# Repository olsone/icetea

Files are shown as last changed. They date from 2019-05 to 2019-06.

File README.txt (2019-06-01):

===== Compiling =======

To compile chip.bin:

make

To send it to BlackIce-II (standard firmware)

Terminal 1:
cat < /dev/cu.usbmodem1421
or:
make tty

Terminal 2:
stty -f /dev/cu.usbmodem1421 raw
cat chip.bin > /dev/cu.usbmodem1421
or:
make upload

stored in blackice.mk

======= PLL =========

Colorburst frequency of 315/88 MHz is made (x8 factor) by:

icepll -o 28.636363 -i 100 -m -f pll_ntsc.v

F_PLLIN:   100.000 MHz (given)
F_PLLOUT:   28.636 MHz (requested)
F_PLLOUT:   28.646 MHz (achieved)

FEEDBACK: SIMPLE
F_PFD:   16.667 MHz
F_VCO:  916.667 MHz

DIVR:  5 (4'b0101)
DIVF: 54 (7'b0110110)
DIVQ:  5 (3'b101)

FILTER_RANGE: 1 (3'b001)

	reg [5:0] count;

//	assign gplclock_out = count[2]; // 3.579545 MHz,  actual 3.580750
	assign sndclock_out = count[5]; // 447.443 KHz, actual 447.593 KHz

	always @(posedge clock8x)
	    if (!locked)
	        count = 0;
	    else
		    count <= count + 1;

========================

Pin assignments in icetea.pcf are customized from blaceice-ii.pcf

Using PMOD7-12 to connect to the IceTea board
Using PMOD6 to connect to PMOD I2S

========================

Structure

chip.v 
\____pll_ntsc.v
\____memory_interface.v ==/== SRAM
\____sn76489 
     \____i2s

===================

Weird errors

ERROR: Mismatch in directionality for cell port chip.dig_snd_out.mclk: \PMOD [20] <= \dig_snd_out.mclk
caused by assigning Z to it somewhere:
  assign PMOD[20:0] = {20{1'bz}};

Warning: Driver-driver conflict for \dig_snd_out.value [7] between cell $techmap\dig_snd_out.$procdff$1731.Q and constant 1'0 in chip: Resolved using constant.
caused by assigning value=0 in akways(reset) and in always(negedge clk)

shift_ctrl.v:17: Warning: Identifier `\count_n' is implicitly declared.

this might be why shift_reset toggles.
 assign count_n = count + 1; always made shift_reset oscillate.

Shift Registers. Did'nt work consistently until I halved the clock rate to 25 MHz.
It now takes 300 ns to decode the address.
===================

Helpful tools

play many loops of a 1-cycle sample:

sox AKWF_symetric/AKWF_symetric_0001.wav -d repeat 180

Like
AKWF_piano/AKWF_piano_0001.wav
AKWF_bw_saw/AKWF_saw_0002.wav

sox AKWF_cello/AKWF_cello_0003.wav -d repeat 100 tremolo 6

sox AKWF_violin/AKWF_violin_0005.wav -d repeat 100 

dumpwav ~/Downloads/AKWF_violin/AKWF_violin_0005.wav > waves/wave_violin.mem

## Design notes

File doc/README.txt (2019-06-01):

===== Compiling =======

To compile chip.bin:

make

To send it to BlackIce-II (standard firmware)

Terminal 1:
cat < /dev/cu.usbmodem1421
or:
make tty

Terminal 2:
stty -f /dev/cu.usbmodem1421 raw
cat chip.bin > /dev/cu.usbmodem1421
or:
make upload

stored in blackice.mk

======= PLL =========

Colorburst frequency of 315/88 MHz is made (x8 factor) by:

icepll -o 28.636363 -i 100 -m -f pll_ntsc.v

F_PLLIN:   100.000 MHz (given)
F_PLLOUT:   28.636 MHz (requested)
F_PLLOUT:   28.646 MHz (achieved)

FEEDBACK: SIMPLE
F_PFD:   16.667 MHz
F_VCO:  916.667 MHz

DIVR:  5 (4'b0101)
DIVF: 54 (7'b0110110)
DIVQ:  5 (3'b101)

FILTER_RANGE: 1 (3'b001)

	reg [5:0] count;

//	assign gplclock_out = count[2]; // 3.579545 MHz,  actual 3.580750
	assign sndclock_out = count[5]; // 447.443 KHz, actual 447.593 KHz

	always @(posedge clock8x)
	    if (!locked)
	        count = 0;
	    else
		    count <= count + 1;

========================

Pin assignments in icetea.pcf are customized from blaceice-ii.pcf

Using PMOD7-12 to connect to the IceTea board
Using PMOD6 to connect to PMOD I2S

========================

Structure

chip.v 
\____pll_ntsc.v
\____memory_interface.v ==/== SRAM
\____sn76489 
     \____i2s

===================

Testbench

brew install icarus-verilog

cat > testbench.mk

shift_tb: shift_ser_in.v shift_tb.v shift74ls165.v
				iverilog -o $@ shift_ser_in.v shift_tb.v shift74ls165.v

make shift_tb

vvp shift_tb

===================

Weird errors

ERROR: Mismatch in directionality for cell port chip.dig_snd_out.mclk: \PMOD [20] <= \dig_snd_out.mclk
caused by assigning Z to it somewhere:
  assign PMOD[20:0] = {20{1'bz}};

Warning: Driver-driver conflict for \dig_snd_out.value [7] between cell $techmap\dig_snd_out.$procdff$1731.Q and constant 1'0 in chip: Resolved using constant.
caused by assigning value=0 in akways(reset) and in always(negedge clk)

shift_ctrl.v:17: Warning: Identifier `\count_n' is implicitly declared.

this might be why shift_reset toggles.
 assign count_n = count + 1; always made shift_reset oscillate.

Shift Registers. Did'nt work consistently until I halved the clock rate to 25 MHz.
It now takes 300 ns to decode the address.

BUG Icarus says
  shift_ser_in ser1 (.i_q(adrin1), .i_reset(o_shld), .i_serclk(o_serclk), .o_data(addr_reg[15:8]))
memory_interface.v:297: error: Output port expression must support continuous assignment.
memory_interface.v:297:      : Port 4 (o_data) of shift_ser_in is connected to addr_reg['sd15:'sd8]

addr_reg cannot be a reg. Change to wire. ADDRESS_DECODE can unscramble it into a reg.

BUG
Warning: multiple conflicting drivers for chip.\mem.chip_select:
did you write 'else' not 'else begin/end':
if (reset) begin
  a = 0;
  b = 0;
  end else
  a = 0
b = 0
   
===================

Helpful tools

play many loops of a 1-cycle sample:

sox AKWF_symetric/AKWF_symetric_0001.wav -d repeat 180

Like
AKWF_piano/AKWF_piano_0001.wav
AKWF_bw_saw/AKWF_saw_0002.wav

sox AKWF_cello/AKWF_cello_0003.wav -d repeat 100 tremolo 6

sox AKWF_violin/AKWF_violin_0005.wav -d repeat 100 

dumpwav ~/Downloads/AKWF_violin/AKWF_violin_0005.wav > waves/wave_violin.mem

================
Signal integrity
================
Confirmed that IAQ is good, and there is a crosstalk glitch in the VB cable.

snapshots 12/4/18 9:24 pm
1) iaq (mistakenly connected on d30 bmemen)

===
decode
56c4 = 7d01 read iaq
56d4 = 7d03 read 
56cc = 7d05 read iaq
56dc = 7d07 read
56e4 = 7d09 read iaq
56f4 = 7d0b read 
4c00 = a001 read
4c00 = a001 write
56ec = 7d0d read

perfect!

0400 = 0001 read
04d0 = 0c03 read iaq
04f0 = 0c0b read iaq

BLWP @>0000

0400 = 0001 read
af3b = 83ff write, so WP = 83E0 
af2b = 83fd write
af33 = 83fb write
0410 = 0003 read 
0409 = 0025 read iaq

0400 = 0001 read
0400 = 0001 read iaq
0410 = 0003 read
0409 = 0025 read
bc18 = c247 read

...

af01 = 83e1 read IAQ
051b = 00b7 read
bc18 = c247 write

0523 = 00b9 read
a77b = 0bff read IAQ
3c29 = c22d write

... last instruction

0c44 = 9801 read 

FREEZING - f18a title displays - the last thing executed was read from GRMRD
icetea is trying to respond at every address.

in VB, srclk glitches, shifting addr right one bit

8641 = 0961 read iaq
af31 = 83eb
a473 = 0a7b

  LIMI 0
  SETO @>A000
  JMP $-4
  
encoded / decoded / memory content  
 7D00  0300
 7D02  0000
56cc 7D04  0720 read iaq
56DC 7D06  A000 read
56E4 7D08  10FD read iaq

4c00 a001
4800 a000

spis addr page
4800 a000 8 wrong
56cc 7d05 c wrong
56cc 7d05 4 wrong
56dc 7d07 7 wrong
56dc 7d07 6 wrong
4800 a000  
56cc 7d05 4 wrong
4c00 a001 0 wrong
56e4 7d09 8 wrong
56cc 7d05 4 wrong

af11 83e3 2 wrong
a62b 037d 2 wrong
261b 0337 2 wrong
2623 0339 2 wrong
af30 83cb a wrong
2721 03a9 2 wrong

Next iteration. use wire addr_in, not reg addr_reg

spis addr page
af11 83e3 a wrong
af21 83e9 a wrong

a62b 037d 2 wrong
4c00 a001 a right
56cc 7d05 7 right
8642 0951 2 wrong
261b 0337 2 wrong

maybe internal cycle is too fast?
8409 0064 xx6x
8421 0068 xx6x 
8403 0070 xx7x
842b 007c xxxC
843a 005e xxxE
2528 028c xxxC
2530 028a xExx
251a 0296 xExx
2522 0298 xExx
2623 0339 2xxx
2633 033a 2x1A
263b 033e xxxE
a618 0347 2xxx

ae2b 837c xx7x
af32 83da xFxx
af11 83e2 Axxx
af21 83e9 AFxx wrong
af31 83ea xFxx
af29 83ec xFEC
af13 83f3 xFxA
af23 83f8 Axxx
af33 83fb xFFx

0cd4 9c02 xx4x  GRMWA
0c44 9800 xExx  GRMRD
read from 9c02: 2 us
write to 9c02: 10 us
read from 9800: 10 us

almost like its not unscrambling the top byte

i moved leds to the bottom of chip.v and in page 0 addresses
8409 0064 x0xx
8419 x0xx
af29 83ec x0xx
af33 83fb x0xx
0cd4 xCxx

test writes to all pages
7D00 LIMI 0
7D02 
7D04 CLR R0

Spi  Addr

56dc 7D06 SETO *R0
56E4 7D08 AI R0,>2000
56f4 7D0A
56ec 7D0C JMP $-8

0400 0 2
0404 1 3
4400 2 2
4404 3 3
1400 4 6
1404 5 7
5400 6 6
5404 7 7
0c00 8 a
0c04 9 b
4c00 a a
4c04 b b
1c00 c e
1c04 d f
5c00 e e
5c04 f f

A2 / BIT 13 is stuck on.
Look at the input to 165.

replaced 165

Measured A2 at 40-pin header. Captured transition 0->1 in 7D07.

It sure looks like it is shorted to A15

try cutting the cruout trace at the source?

oops

8b11 -> 81e2
this should be 83e2
definitely cut a15, but also a6, which was next to it.
this can't be a hardware issue because SPI looks perfect. 
SOLVED (shift register would get stuck by initializer to all 1s)
========================================

RAM
1. CRASH icetea is supplying databus when CPU is reading an instruction from page 0
chip_select logic was backwards!

2. case for chip_select was in its own always block, moved it into main state block.
that fixed an issue that state would get stuck in MEM_WRITE.

returning 1234 from memory shows as 1c84
1234 1c84
8888 2222
4000 0001
2000 0008

 INC *R5       read, inc, write
 MOV *R5,R4    read back
 BL @A2        display
 
 (lsb first, a15 high)
read:  10 00
write: 12 00
read:  00 12

 (lsb first, a15 high)
read:  00 10
write: 02 10
read:  02 10

newest

f000 0f00
0f00 f000
00f0 000f
000f 00f0
8000 0200
4000 0100
2000 0800
1000 0400

rewrote pcf file
was     20563147

8040 4080

rewrote 46305721
8040 8040
2010 2010
0804 0804
0201 0201
all correct

Scope
ABCD CE57
1010 1011 1100 1101
1100 1110 0101 0111

8040 4080
8041 4082

swap test pins:
(msb first)
8040 8040
8041 8041

=============
read 00 20 = 2000
write 01 20 = 2001
read 01 20 = 2001

can see instruction on data bus during IAQ
c115 mov *r5,r4

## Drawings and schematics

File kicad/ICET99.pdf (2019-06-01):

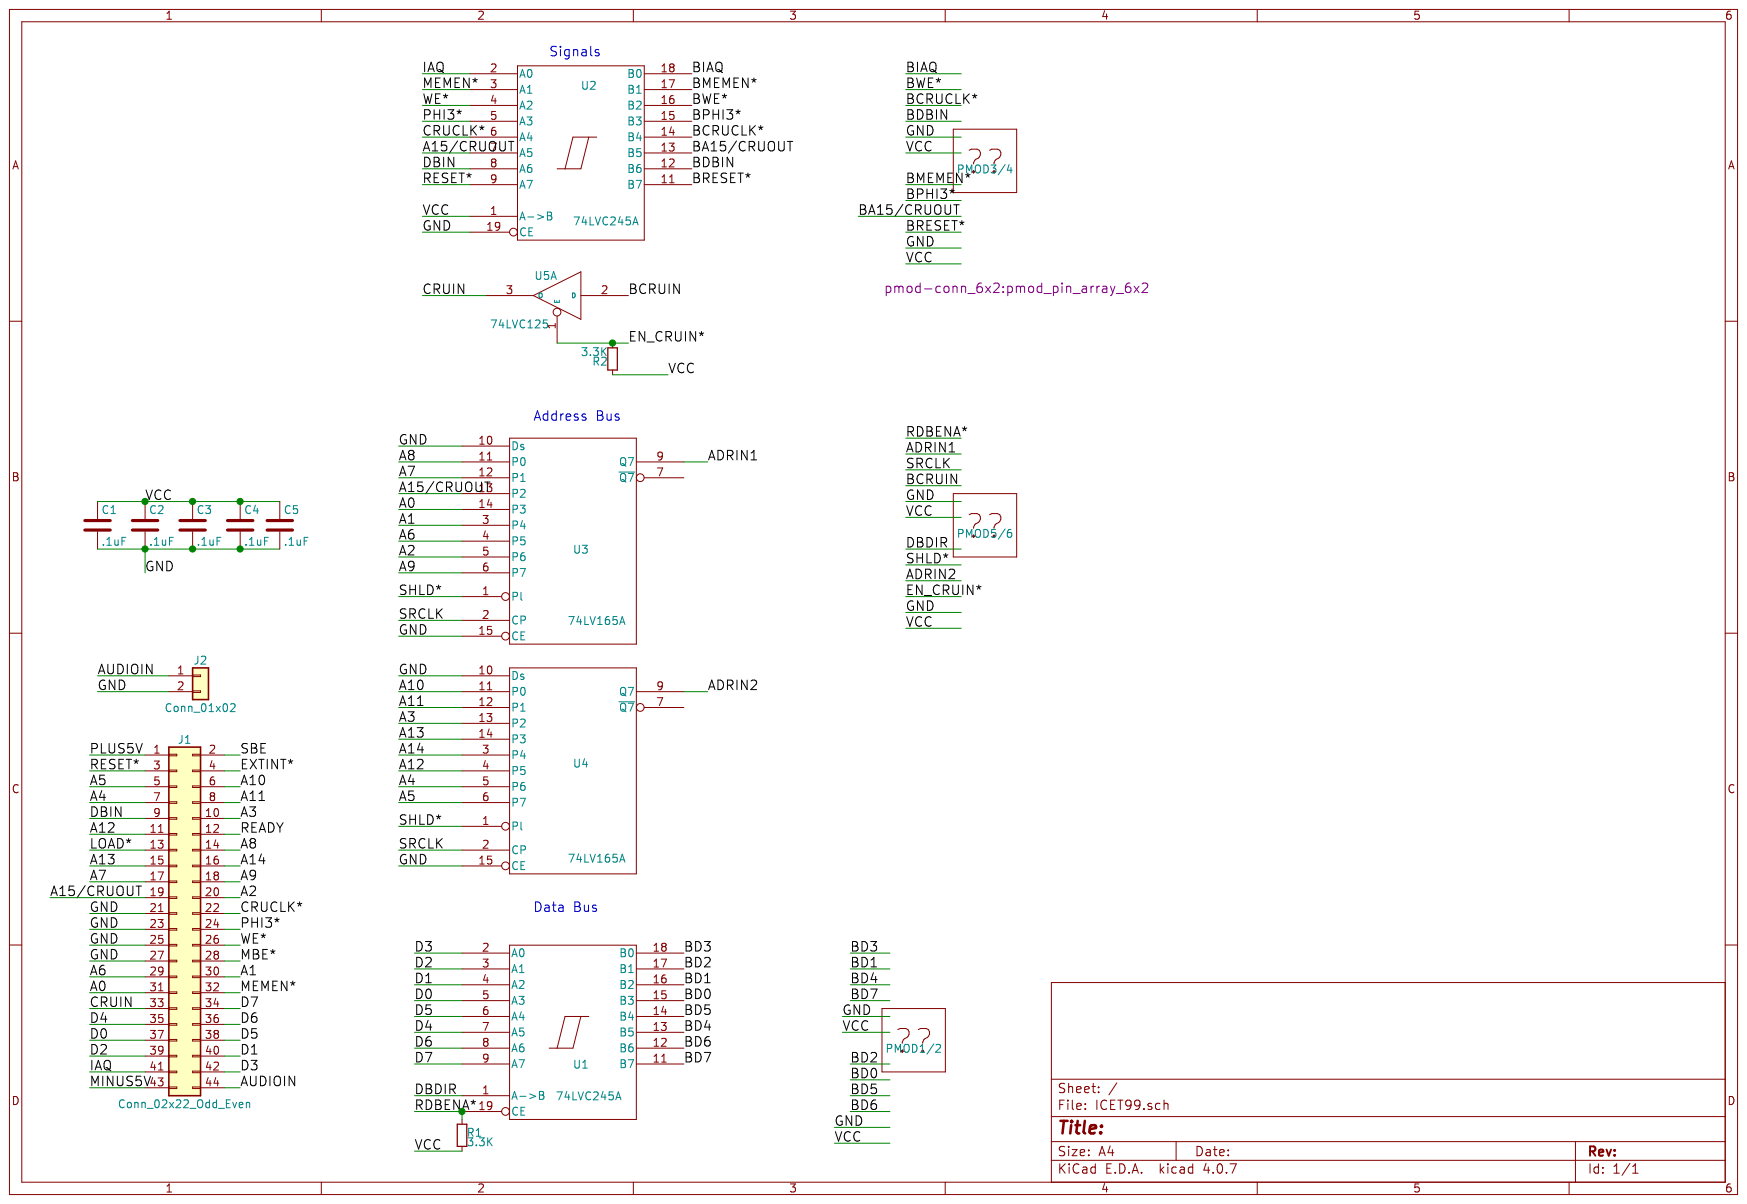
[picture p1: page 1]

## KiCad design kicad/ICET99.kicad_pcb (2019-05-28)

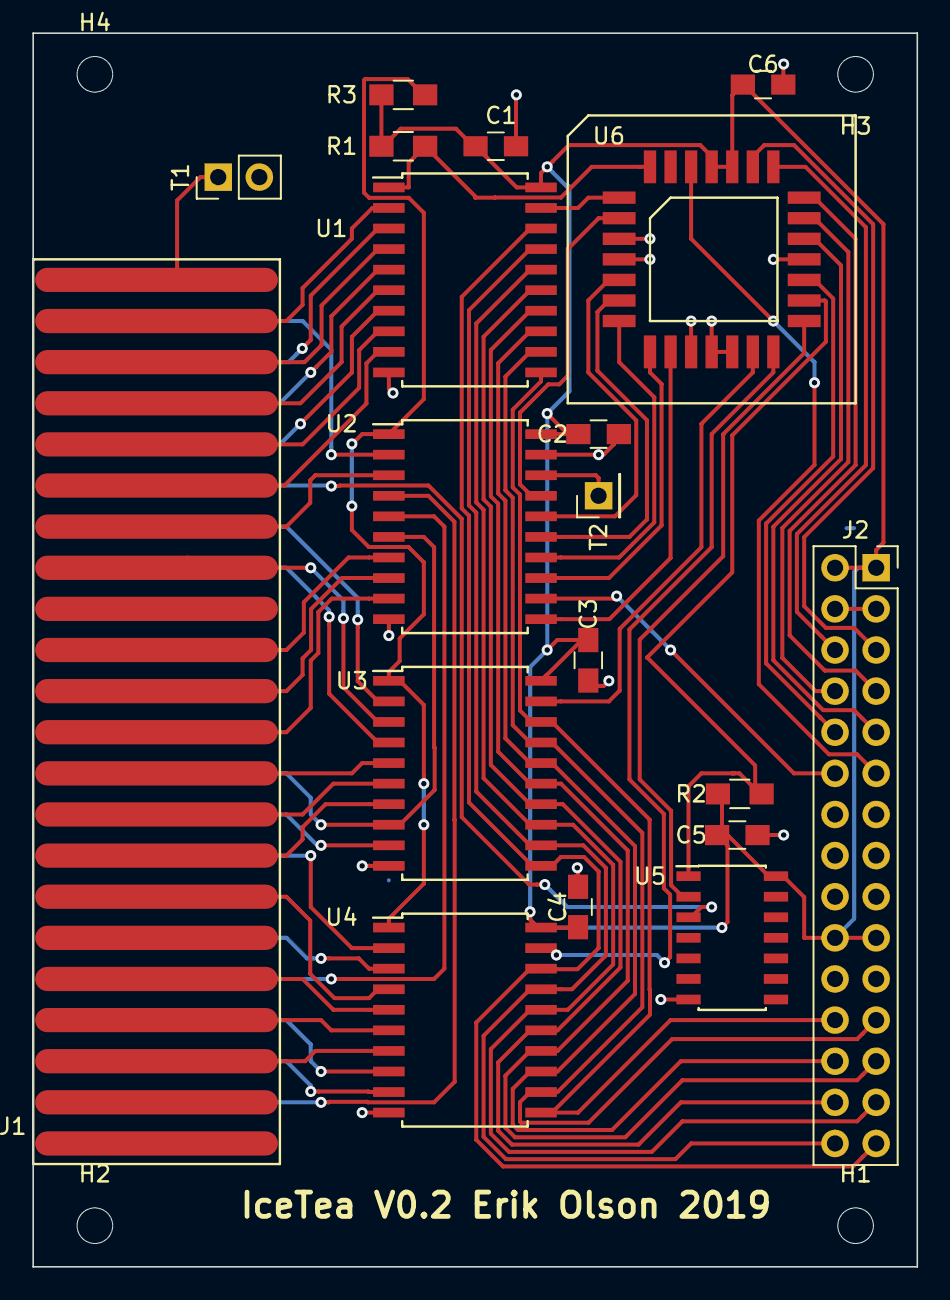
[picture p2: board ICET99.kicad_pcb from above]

Board: 2 copper layers, 54.6 x 76.2 mm, 23 parts (0 on the bottom side), 65 nets.

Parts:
C1, C2, C3, C4, C5, C6: .1uF; C_0805_HandSoldering
H1, H2, H3, H4: MountingHole; MountingHole_2.2mm_M2
J1: Conn_02x22_Odd_Even; Card_Edge_2x22
J2: MxMod-Device; Socket_Strip_Straight_2x15_Pitch2.54mm
R1, R2, R3: 3.3K; R_0805_HandSoldering
T1: Conn_01x02; Pin_Header_Straight_1x02_Pitch2.54mm
T2: Conn_01x02; Pin_Header_Straight_1x01_Pitch2.54mm
U1, U2, U3, U4: 74LVC245A; SOIC-20W_7.5x12.8mm_Pitch1.27mm
U5: 74HCT125; SOIC-14_3.9x8.7mm_Pitch1.27mm
U6: ATF22LV10C-28J; PLCC-28

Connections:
+3V3: C1.1, C2.1, C3.1, C4.1, C5.1, C6.1, J2.1, J2.2, J2.19, J2.20, R1.2, R2.1, R3.2, U1.20, U2.20, U3.20, U4.20, U5.14, U6.1, U6.28
/A0: J1.31, U3.2
/A1: J1.30, U3.3
/A2: J1.20, U3.5
/A3: J1.10, U4.5
/A4: J1.7, U4.8
/A5: J1.5, U4.9
/A6: J1.29, U3.4
/A7: J1.17, U3.9
/A8: J1.14, U4.4
/A9: J1.18, U3.6
/A10: J1.6, U4.7
/A11: J1.8, U4.6
/A12: J1.11, U4.3
/A13: J1.15, U4.2
/A14: J1.16, U3.7
/A15CRUOUT: J1.19, U2.6, U3.8
/ABEN1: U3.19, U6.17
/ABEN2: U4.19, U6.18
/AUDIOIN: J1.44, T1.1
/BA15CRUOUT: U2.14, U6.11
/BCRUCLK: U2.11, U6.13
/BD0: J2.28, U1.15, U3.14, U4.15
/BD1: J2.27, U1.16, U3.13, U4.16
/BD2: J2.30, U1.17, U3.12, U4.17
/BD3: J2.29, U1.18, U3.11, U4.18
/BD4: J2.26, U1.13, U3.16, U4.13
/BD5: J2.25, U1.14, U3.15, U4.14
/BD6: J2.23, U1.12, U3.17, U4.12
/BD7: J2.24, U1.11, U3.18, U4.11
/BDBIN: U2.15, U6.10
/BIAQ: T2.1, U2.18
/BMEMEN*: U2.17, U6.6
/BPHI3*: J2.12, U2.12
/BRESET*: U2.16, U6.9
/BWE*: U2.13, U6.12
/CLKIN: J2.11, U6.2
/CRUBIT: U5.2, U6.19
/CRUCLK: J1.22, U2.9
/CRUEN: R2.2, U5.1, U6.20
/CRUIN: J1.33, U5.3
/D0: J1.37, U1.5
/D1: J1.40, U1.4
/D2: J1.39, U1.3
/D3: J1.42, U1.2
/D4: J1.35, U1.7
/D5: J1.38, U1.6
/D6: J1.36, U1.8
/D7: J1.34, U1.9
/DBDIR: R1.1, U1.1, U6.4
/DBEN1: U1.19, U6.5
/DBIN: J1.9, U2.5
/DEC0: J2.8, U6.24
/DEC1: J2.9, U6.23
/DEC2: J2.10, U6.21
/ENC0: J2.7, U6.25
/ENC1: J2.6, U6.26
/ENC2: J2.5, U6.27
/IAQ: J1.41, U2.2
/MEMEN*: J1.32, U2.3
/PHI3*: J1.24, U2.8
/RESET*: J1.3, U2.4
/WE*: J1.26, U2.7
GND: C1.2, C2.2, C3.2, C4.2, C5.2, C6.2, J1.21, J1.23, J1.25, J1.27, J2.3, J2.4, J2.21, J2.22, T1.2, U1.10, U2.10, U2.19, U3.10, U4.10, U5.7, U6.7, U6.8, U6.14, U6.15, U6.16, U6.22
unnamed: R3.1, U2.1, U3.1, U4.1

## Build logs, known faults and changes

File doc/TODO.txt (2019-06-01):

Modest goals

assign pin names from the pcf file

read the control signals, blink lights on memen, we*, dbin*

print a msg to serial for test pass/fail

read the memory bus, light led if you see a particular address

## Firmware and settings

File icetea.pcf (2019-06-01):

###############################################################################
#                                                                             #
# Copyright 2017 myStorm Copyright and related                                #
# rights are licensed under the Solderpad Hardware License, Version 0.51      #
# (the “License”); you may not use this file except in compliance with        #
# the License. You may obtain a copy of the License at                        #
# http://solderpad.org/licenses/SHL-0.51. Unless required by applicable       #
# law or agreed to in writing, software, hardware and materials               #
# distributed under this License is distributed on an “AS IS” BASIS,          #
# WITHOUT WARRANTIES OR CONDITIONS OF ANY KIND, either express or             #
# implied. See the License for the specific language governing                #
# permissions and limitations under the License.                              #
#                                                                             #
###############################################################################

# User Constraint File for myStorm BlackIce II   - Ken Boak   09-12-17

#pmod 1 (Uart pmod)
set_io PMOD[0] 94 # rd6
set_io PMOD[1] 91 # rd4 shared with RTS and pin 128 see below
set_io PMOD[2] 88 # rd2
set_io PMOD[3] 85 # rd0

#pmod 2
set_io PMOD[4] 95 # rd7
set_io PMOD[5] 93 # rd5
set_io PMOD[6] 90 # rd3
set_io PMOD[7] 87 # rd1

#pmod 3 GPIO
set_io PMOD[8] 105 # c5
set_io PMOD[9] 102 # c3
set_io PMOD[10] 99 # c1
set_io PMOD[11] 97 # i_tx

#pmod 4
set_io PMOD[12] 104 # c4
set_io PMOD[13] 101 # c2
set_io PMOD[14] 98 # c0
set_io PMOD[15] 96 # i_rx

#pmod 5 GPIO
# dig snd extra
set_io PMOD[16] 143 #g2
set_io PMOD[17] 114 #c11
set_io PMOD[18] 112 #c9
set_io PMOD[19] 107 #c7

#pmod 6 GPIO
# i2s 
set_io PMOD[20] 144 #G1
set_io PMOD[21] 113 #C10
set_io PMOD[22] 110 #C8
set_io PMOD[23] 106 #C6

#pmod 7 lvds pairs 2 & 5
set_io RDBENA   10 # 5b    o
set_io ADRIN1    9 # 5a    i
set_io SRCLK     2 # 2b    i
set_io BCRUIN    1 # 2a    o

#pmod 8 lvds pairs 3 & 4
set_io DBDIR     8 # 4b    o
set_io SHLD      7 # 4a    o
set_io ADRIN2    4 # 3b    i
set_io EN_CRUIN  3 # 3a    o

#pmod 9 lvds pairs 10 & 13
set_io BIAQ     20 # 13b   i
set_io BWE      19 # 13a   i
set_io BCRUCLK  16 # 10b   i
set_io BDBIN    15 # 10a   i

#pmod 10 lvds pairs 8 & 12
set_io BMEMEN   18 # 12b   i
set_io BPHI3    17 # 12a   i
set_io BCRUOUT  12 # 8b    i
set_io BRESET   11 # 8a    i


#pmod 11 lvds pairs 14 & 25
set_io BDB[4]   34 # 25b  io 
set_io BDB[6]   33 # 25a  io
set_io BDB[3]   22 # 14B  io 
set_io BDB[0]   21 # 14a  io  

#pmod 12 lvds pairs 18 & 24
set_io BDB[5]   32 # 24b  io
set_io BDB[7]   31 # 24a  io
set_io BDB[2]   26 # 18b  io
set_io BDB[1]   25 # 18a  io 

#pmod 13 DIG16-DIG19
# i2s didn't work out here. were all the switches grounded? try again
set_io PMODC[0] 37  # DIG19
set_io PMODC[1] 38  # DIG18
set_io PMODC[2] 39  # DIG17
set_io PMODC[3] 41  # DIG16

#pmod 14 SPI muxed with leds
set_io PMODC[4] 71 #LD4,!SS,p14_1
set_io PMODC[5] 67 #LD3,MISO,p14_2
set_io PMODC[6] 68 #LD2,MOSI,p14_3
set_io PMODC[7] 70 #LD1,SCL,p14_4
# Buttons
set_io B1 63 # Push Button 1
set_io B2 64 # Push Button 2#


# SRAM
set_io ADR[0] 137
set_io ADR[1] 138
set_io ADR[2] 139
set_io ADR[3] 141
set_io ADR[4] 142
set_io ADR[5] 42
set_io ADR[6] 43
set_io ADR[7] 44
set_io ADR[8] 73
set_io ADR[9] 74
set_io ADR[10] 75
set_io ADR[11] 76
set_io ADR[12] 115
set_io ADR[13] 116
set_io ADR[14] 117
set_io ADR[15] 118
set_io ADR[16] 119
set_io ADR[17] 78

set_io DAT[0] 136
set_io DAT[1] 135
set_io DAT[2] 134
set_io DAT[3] 130
set_io DAT[4] 125
set_io DAT[5] 124
set_io DAT[6] 122
set_io DAT[7] 121
set_io DAT[8] 62
set_io DAT[9] 61
set_io DAT[10] 60
set_io DAT[11] 56
set_io DAT[12] 55
set_io DAT[13] 48
set_io DAT[14] 47
set_io DAT[15] 45

set_io RAMOE 29
set_io RAMWE 120
set_io RAMCS 23
set_io RAMUB 28
set_io RAMLB 24

# QUAD SPI
set_io QSPICSN 81
set_io QSPICK 82
set_io QSPIDQ[0] 83
set_io QSPIDQ[1] 84
set_io QSPIDQ[2] 79
set_io QSPIDQ[3] 80

# Debug
set_io DONE 52 # DONE - GBIN4
set_io DBG1 49 # DBG1 - GBIN5

# Internal global reset
set_io greset 128 # Connected to CH340 RTS and also P1 (uart Pmod above)

# Onboard 100Mhz oscillator
set_io clk 129

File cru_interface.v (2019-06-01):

/*  cru_interface implements the paging in and out of DSR roms and SAMS memory, and potentially more.

  In a 9900 computer architecture, CRU "communications register unit" is a separate interface bus between
  the 9900 and 9901 (programmable systems interface) and external peripherals. It uses 
  the A0-A14 address bus and transfers 1-bit serial data over CRUIN, CRUOUT(A15) gated by CRUCLK.

  CRU instructions in the 9900 are: 
    SBO d     set bit one
    SBZ d     set bit zero
    TB  d     test bit (read one bit from cru)
    LDCR s,n  load n cru bits into cru from s (set multiple bits/write to cru)
    STCR s,n  store n cru bits from cru into s (read multiple bits from cru)
  CRU instructions use R12 as the base address (only bits A0-A14)
  For single bit intructioms, the CRU adress is R12 (A0-A14) + d (signed)
   
  Peripherals on the expansion bus each have a CRU base address from $1000 to $1f00, and 
  respond to CRU instructions.
  Each peripheral can have 128 bits of address space.
  Their DSR ROMs are paged in at $4000 by setting a 1 at their CRU base address.
  A device scan pages in each one at a time.
  
  It is customary to enable this bit even if the rom is not used, 
  so that a led will show device activity. For instance direct RS232 access has no
  need of the rom, but blinking the led is desirable.

  Peripherals have other registers mapped into their CRU address space. For instance the 
  RS232 has UART registers.

  They may have registers in the CPU address space as well. Disk controller has WD1771
  IO registers, SAMS has LS612 memory mapper registers.
  
  Some known peripherals:
   >1000 HFDC, WDS, HRD, any storage device taking priority over FDCC
   >1100 FDCC Floppy Disk Controller
   >1300 RS232
  
    LD R12,>1300
    SBO 0    page in the rs232 DSR ROM at >4000. 
    TB  7    test for some bit
    JEQ YES
    SBZ 0    page out
    ...
     
*/

module cru_interface(
  input wire clk,
  input wire reset,
  input wire i_memen,
  input wire i_cruclk,
  
  input wire [12:0] i_cru_address, // cpu address lines A3-A14 (indexed 13:1 out there)
  input wire i_cruout, // cpu address line A15/CRUOUT
  output wire o_cruin,
  output wire o_en_cruin,
  
  // 74LS612 peripheral, connected to memory_interface
  input  wire [3:0] i_bank_sel,
  output wire o_bank_mapped,
  output wire o_bank_readonly,
  output wire [6:0] o_bank_address
  
  );
  
  
  // The CPU memory address model is based on the SuperAMS peripheral.
  // http://www.unige.ch/medecine/nouspikel/ti99/superams.htm
  // which is based on the 74LS612 memory mapper.
  // SuperAMS uses the upper 4 bits of the address, but responds only at $2000,$3000, and $a000-$f000.
  // I will allow paging of 4k at $5000 or $7000 (or anywhere else), as there is one 512K memory
  // used for dsr roms, cartridge rom, and ram.
  //
  // SuperAMS has two cru bits:
  // bit0 - cardsel
  // bit1 - transparent mode (no substitution)
  
  // idea:
  // TODO: A write to an even number register has the side effect of setting the next odd register 1 page higher.
  //
  // to set registers, activate the AMS card (set bit at $1e00) and write 8 bit value to cpu memory $40xx (address bits A11-A14 = bank_sel)
  //
  // figure this out:
  // writes to memory need to pass through to registers in the DSR space. 
  // mem_interface decodes cpu memory cycles...
  // this module could also interpret writes to DSR space, and bank switching module space.

  reg  sams_transparent; // bit1
  wire sams_memexp;
  reg  [15:0] cru_cardsel;    // cru bit 0 for each card to enable it
  
  wire sams_cardsel = cru_cardsel[14]; // cru address $1E00

  // address banking.
  // there are 16x4k in address space. there are a possible 128 4k pages in SRAM.
  reg [1:0]  bank_flags[15:0]; // 00 not mapped, 01 not mapped, 10 ram, 11 rom 
  reg [6:0]  bank_address[15:0]; // upper 7 bits of real address. 74LS612 has 12 bits.
    
    // iceTea uses the SRAM as follows (the first 64k is very like a basic 4A): 
    // 4k page number, use
    // ---------------------
    // 00 reserved (bug catcher) 
    // 02 low ram
    // 04 icetea main dsr rom 
    // 06 cartridge rom
    // 08 reserved
    // 0a high ram
    // 0c high ram
    // 0e high ram
    // 10 superams ram 
    // 7f " 
    //
    // other needs: 
    // SD buffer (reduce demand on BRAM)
    // how does J1 access the sram? can the J1 only access it through an I/O port.
  wire is_memexp;
  
  assign is_memexp = i_bank_sel[3:1]==3'b001 || i_bank_sel[3:1]==3'b101 || i_bank_sel[3:2]==2'b11; 
			
  assign o_bank_mapped   = sams_transparent ? is_memexp  : bank_flags[i_bank_sel][1];
  assign o_bank_readonly = sams_transparent ? !is_memexp : bank_flags[i_bank_sel][0];
  assign o_bank_address  = sams_transparent ? {3'b000,i_bank_sel} : bank_address[i_bank_sel];


  // CRU cycles not implemented
  assign o_en_cruin = 1'b1;
  assign o_cruin    = 1'b0;
  
  always @(posedge i_cruclk or posedge reset) begin
		if (reset) begin
			
			sams_transparent = 1'b1;
			// use default memory map?
			cru_cardsel = 16'h0000; // all cards off. only one at a time should ever be enabled!
			bank_flags[0]  <= 2'b00;
			bank_flags[1]  <= 2'b00; // $0000 console rom
			bank_flags[2]  <= 2'b10;
			bank_flags[3]  <= 2'b10; // $2000 low ram
			bank_flags[4]  <= 2'b00;
			bank_flags[5]  <= 2'b00; // $4000 dsr rom or ram
			bank_flags[6]  <= 2'b00;
			bank_flags[7]  <= 2'b00; // $6000 cart rom
			bank_flags[8]  <= 2'b00;
			bank_flags[9]  <= 2'b00; // $8000 console memory mapped space
			bank_flags[10] <= 2'b10;
			bank_flags[11] <= 2'b10; // $A000 high ram
			bank_flags[12] <= 2'b10;
			bank_flags[13] <= 2'b10; // $C000 high ram
			bank_flags[14] <= 2'b10;
			bank_flags[15] <= 2'b10; // $E000 high ram
		
			bank_address[0]  = 7'h00;
			bank_address[1]  = 7'h00; // $0000 console rom
			bank_address[2]  = 7'h02;
			bank_address[3]  = 7'h03; // $2000 low ram
			bank_address[4]  = 7'h00;
			bank_address[5]  = 7'h00; // $4000 dsr rom
			bank_address[6]  = 7'h00;
			bank_address[7]  = 7'h00; // $6000 cart rom
			bank_address[8]  = 7'h00;
			bank_address[9]  = 7'h00; // $8000 memory mapped space
			bank_address[10] = 7'h04;
			bank_address[11] = 7'h05; // $A000 high ram
			bank_address[12] = 7'h06;
			bank_address[13] = 7'h07; // $C000 high ram
			bank_address[14] = 7'h08;
			bank_address[15] = 7'h09; // $E000 high ram
		
		end else 
			if (i_memen) begin // possibly a CPU memory cycle, but let memory_interface tell us
		
      end
  end
endmodule

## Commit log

2018-05-25 SweetTea schematic
    [ICET99.kicad_pcb, ICET99.sch]
2018-09-11 Pdf of schematic
2018-12-11 Checkpoint. Console memory cycle gives wrong page# still
    [cru_interface.v, icetea.pcf]
2019-01-05 data bus all correct in pcf
    [icetea.pcf]
2019-05-28 PCB design for v0.2
    [ICET99.kicad_pcb, ICET99.sch]
2019-07-19 Updated schematic
    [ICET99.sch]
